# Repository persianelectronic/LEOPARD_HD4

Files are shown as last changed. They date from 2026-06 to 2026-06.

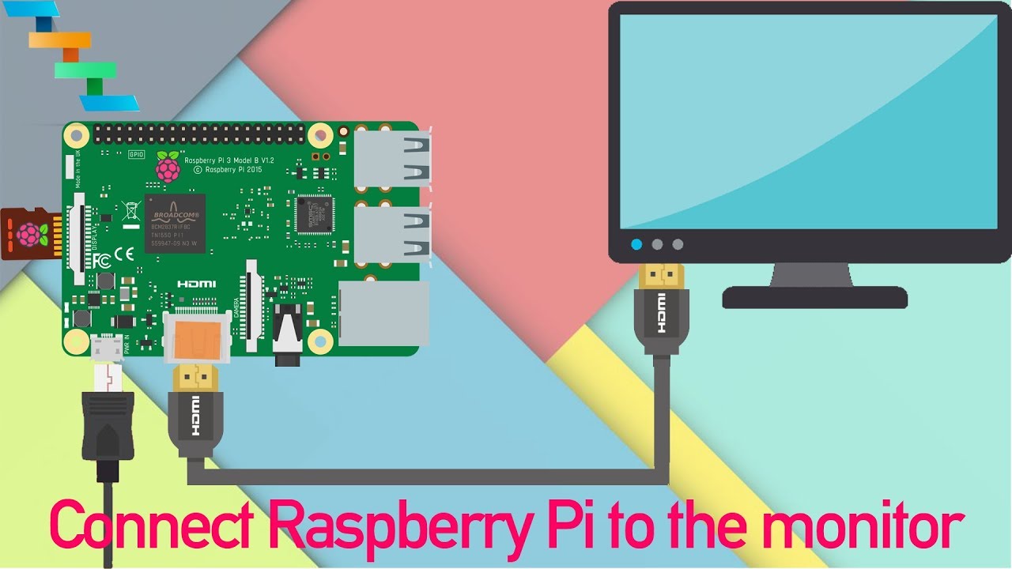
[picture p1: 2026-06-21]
Image/HDMI TI MONITOR.jpg

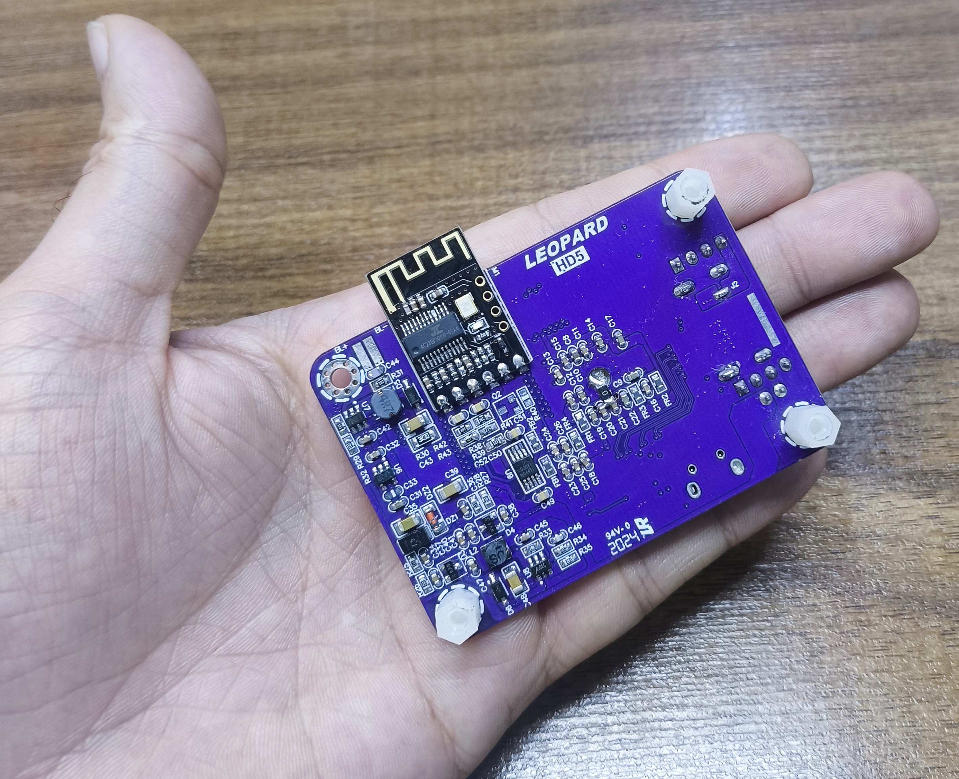
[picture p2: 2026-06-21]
Image/IMG_20260621_094336.jpg

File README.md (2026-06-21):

s-l400Texas Instruments_TFP401AIPZPR-1_2736

612SBk9E+4L

HDMI

#### 📂 فایل‌های پروژه

- 🟣 انتشار رایگان فایل‌های شماتیک (Schematic) و PCB  
- 🟣 ارائه فایل‌های اصلی پروژه در Altium Designer  
- 🟣 دسترسی به فایل‌های تولید برد (Gerber) و مستندات فنی  
- 🟣 طراحی کاملاً متن‌باز و قابل توسعه برای همگان  

<br>

- 🟣 ارائه کامل فایل‌های EDID و فایل‌های باینری آماده  
- 🟣 آموزش برنامه‌ریزی و شخصی‌سازی EDID با آردوینو  
- 🟣 مستندات فنی جهت راه‌اندازی و توسعه پروژه  

<br>

#### ⚙️ مشخصات فنی

- 🟣 مبتنی بر تراشه قدرتمند TFP401 از شرکت Texas Instruments  
- 🟣 مبدل HDMI/DVI به RGB Parallel برای نمایشگرهای TFT  
- 🟣 طراحی فشرده، کاربردی و قابل تولید  
- 🟣 مناسب برای پروژه‌های آموزشی، تحقیقاتی و صنعتی  

<br>

#### 🎯 کاربردها

- 🟣 مناسب برای مهندسان، دانشجویان و علاقه‌مندان به سیستم‌های امبدد و پردازش تصویر  
- 🟣 ایده‌آل برای توسعه نمایشگرهای TFT مبتنی بر HDMI  
- 🟣 قابل استفاده در پروژه‌های صنعتی، آزمایشگاهی و آموزشی  

<br>

#### 👨‍💻 توسعه‌دهنده

- 🟣 طراحی و توسعه توسط شرکت Persian Electronic Poya  
- 🟣 پروژه‌ای متن‌باز با هدف گسترش دانش سخت‌افزار و اشتراک‌گذاری تجربیات مهندسی  

<br>

#### 🌟 ویژگی‌ها

- 🟣 Open Source Hardware  
- 🟣 Altium Designer Project Files Included  
- 🟣 Free Schematic & PCB Files  
- 🟣 Free EDID Resources  
- 🟣 Powered by Texas Instruments TFP401  

---

<div align="center">

🚀 **سخت‌افزار آزاد • دانش آزاد • آینده‌ای باز** 🚀

</div>



Screenshot (168)
Screenshot (167)
Screenshot (166)
LEOPARD_HD4
Screenshot (169)
Screenshot (171)

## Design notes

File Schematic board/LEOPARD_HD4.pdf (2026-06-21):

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
ب.ظ 08:23:45 30/03/1405

### D:\Project_office\LEOPARD_HD4\LEOPARD_HD4\TOP.SchDoc

### Title:

Size: | Number:

### Date:

### File:

### Revision:

Time: | Sheet | of

A4

Drawn By: saeed kolivand | Checked By: yes

### License: altium Email: pepoya.info@gmail.com

### Page Contents: TOP.SchDoc

### Website:

# TOP

### www.pepoya.ir

# پرشین الکترونیک پویا

# PEPOYA

### CTP

### AMP

### USB_DATA

### TOP MAIN.SchDoc

### TFT USB_DATA

### TOP_TFP401 TFP401.SchDoc

TFT | CTP

### TOP_LCD LCD.SchDoc

### AMP

### TOP_AUDIO AUDIO.SchDoc

### CTP USB_DATA

### TOP_TP TCP.SchDoc

D D

C C

B B

A A

2

1 1
ب.ظ 08:23:45 30/03/1405

### D:\Project_office\LEOPARD_HD4\LEOPARD_HD4\MAIN.SchDoc

### Title:

Size: | Number:

### Date:

### Revision:

Time: | Sheet | of

A4

Drawn By: saeed kolivand | Checked By: yes

### License: altium Email: pepoya.info@gmail.com

### Page Contents: MAIN.SchDoc

### Website:

# MCU

### www.pepoya.ir

# پرشین الکترونیک پویا

# PEPOYA

0.1uF

C2
3V3M | GND

3V3M

### DATA_P

### DATA_N

### USB

### USB_DATA TOP[2B], TCP[3D], TFP401[8A] DATA_N

### DATA_P

### DATA_N

### CH554G

### P3.2/TXD1_/INT0/VBUS1/AIN3 1 P1.4/T2_/CAP1_/SCS/TIN2/UCC1/AIN1 2 P1.5/MOSI/PWM1/TIN3/UCC2/AIN2 3 P1.6/MISO/RXD1/TIN4 4 P1.7/SCK/TXD1/TIN5 5 RST/T2EX_/CAP2_ 6 P3.1/PWM2_/TXD 7 P3.0/PWM1_/RXD 8

P1.1/T2EX/CAP2/TIN1/VBUS2/AIN0 | | | | | | | 9
P3.3/INT1 | 10 P3.4/PWM2/RXD1_/T0 | 11 P3.6/UDP | 12 P3.7/UDM | 13 GND/VSS | 14 VCC/VDD | 15 V33 | 16

U1

### DATA_P

GND | 0603

R2 10K
3V3M

### CTP_INT CTP_SCL CTP_SDA CTP_RST

### TX_MCU RX_MCU

### LED

3V3M

VI 1
INH 3 | BYP | 4
VO | 5 2

### GND

### U2 LN1134-3.3V

10UF
C3

### GND

5.0V | 0603 | C5

### 10NF ⁰⁶⁰³

C4
100NF

### GND

1
2
3
4

### TTL

### HDR1X4

3V3M

### TX_MCU

### RX_MCU

### GREEN

LD1 0603
R1

1K

GND | AMP_EN
3V3M | 0603

R3
10K

### GND

SW1

SW1

# RST_MCU 0603

R5
10K

### GND

RST_MCU | 3V3M

H1

### Round Pad

H2

### Round Pad

16

### AMP

AMP | TOP[2C], AUDIO[1B] AMP_EN

0.1uF

C1

### CTP_SDA CTP_SCL CTP_INT CTP_RST

### EN_BLK

TP

CTP | TOP[2B], LCD[3B]

### CTP_INT

### CTP_SCL

### CTP_SDA

### CTP_RST

### EN_BLK

H4

### Round Pad

H3

### Round Pad

### EN_BLK

### OFF/ON

SW1

### RST

SW2

### BOOT

SW3

### BOOT

EP 101 | Clock And Control | Signals OOD Pixel Output EVEN Pixel Output DVI / HDMI Input TFP401 Config

# VDD⁰⁶⁰³

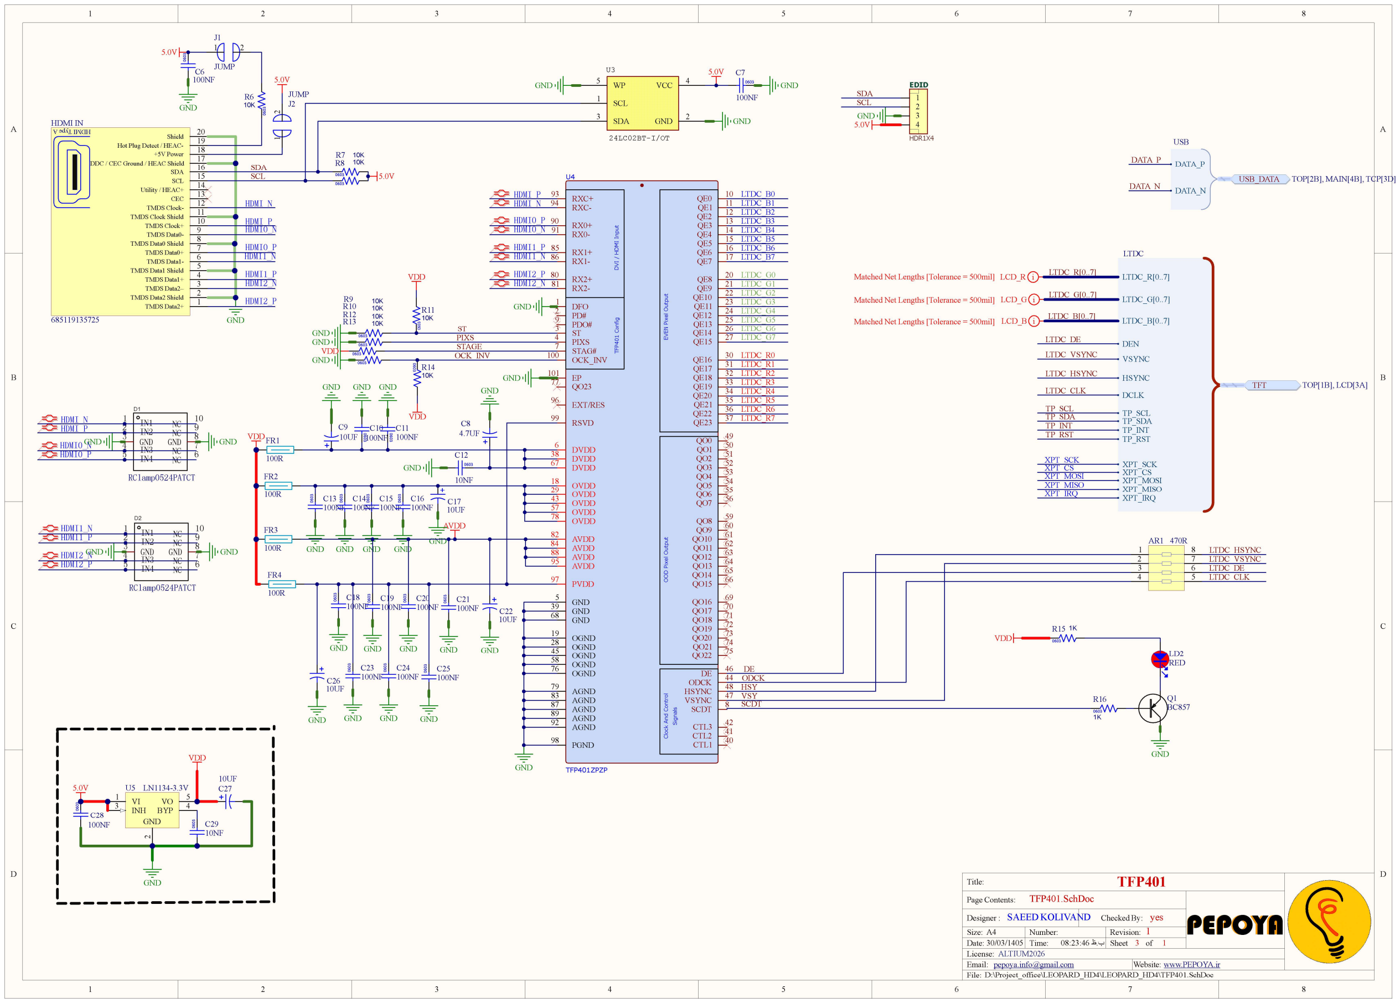
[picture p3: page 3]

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
ب.ظ 08:23:46 30/03/1405

D:\Project_office\LEOPARD_HD4\LEOPARD_HD4\TFP401.SchDoc

Title:

Size: | Number:
Date:

Revision:
Time: | Sheet | of

A4

Designer : SAEED KOLIVAND Checked By: yes

License: ALTIUM2026
Email: pepoya.info@gmail.com

Page Contents: TFP401.SchDoc

Website: www.PEPOYA.ir

# TFP401

# PEPOYA

DFO 1
PD# 2

ST 3
PIXS 4

GND 5

DVDD 6

STAG# 7

SCDT 8

PDO# 9

QE0 | 10
QE1 | 11
QE2 | 12
QE3 | 13
QE4 | 14
QE5 | 15
QE6 | 16
QE7 | 17

OVDD 18

OGND 19

QE8 | 20
QE9 | 21
QE10 | 22
QE11 | 23
QE12 | 24
QE13 | 25
QE14 | 26
QE15 | 27

OGND 28

OVDD 29

QE16 | 30
QE17 | 31
QE18 | 32
QE19 | 33
QE20 | 34
QE21 | 35
QE22 | 36
QE23 | 37

DVDD 38

GND 39

CTL1 | 40 CTL2 | 41 CTL3 | 42

OVDD 43

ODCK 44

OGND 45

DE | | 46
VSYNC | 47 HSYNC | 48
QO0 | 49
QO1 | 50
QO2 | 51
QO3 | 52
QO4 | 53
QO5 | 54
QO6 | 55
QO7 | 56
OVDD 57

OGND 58

QO8 | 59
QO9 | 60
QO10 | 61
QO11 | 62
QO12 | 63
QO13 | 64
QO14 | 65
QO15 | 66

DVDD 67

GND 68

QO16 | 69
QO17 | 70
QO18 | 71
QO19 | 72
QO20 | 73
QO21 | 74
QO22 | 75

OGND 76

QO23 77

OVDD 78

AGND 79

RX2+ 80
RX2- 81

AVDD 82

AGND 83

AVDD 84

RX1+ 85
RX1- 86

AGND 87

AVDD 88

AGND 89

RX0+ 90
RX0- 91

AGND 92

RXC+ 93
RXC- 94

AVDD 95

EXT/RES 96

PVDD 97

PGND 98

RSVD 99

OCK_INV 100

U4

GND | TFP401ZPZP

FR1

100R

FR2

100R

FR3

100R

FR4

100R

R6
10K | 0603 | C19

100NF ⁰⁶⁰³ C20
100NF 0603 | C21 100NF
GND | GND | GND ⁰⁶⁰³ C18
100NF
GND | 0603 | C15 100NF

GND ⁰⁶⁰³ C13
100NF
GND | 0603 | C14 100NF
GND | 0603 | C16 100NF

# GND ⁰⁶⁰³

C10
100NF
GND | 0603

C11
100NF

GND

AVDD

TMDS Data2+ | 1
TMDS Data2 Shield | 2
TMDS Data2– | 3
TMDS Data1+ | 4
TMDS Data1 Shield | 5
TMDS Data1- | 6
TMDS Data0+ | 7
TMDS Data0 Shield | 8
TMDS Data0- | 9
TMDS Clock+ | 10 TMDS Clock Shield | 11 TMDS Clock- | 12 CEC | 13 Utility / HEAC+ | 14 SCL | 15 SDA | 16 DDC / CEC Ground / HEAC Shield | 17 ⁺⁵V Power | 18 Hot Plug Detect / HEAC- | 19 Shield | 20 HDMI Type A

HDMI IN

685119135725

5.0V

SDA
SCL

GND

GND

0603

R8 10K

0603

R7 10K

5.0V

GND

0603

R9 10K

0603

R10 10K

0603

R13 10K

0603

R12 10K

VDD

ODCK
HSY
VSY

LCD_R i

Matched Net Lengths [Tolerance = 500mil]

Matched Net Lengths [Tolerance = 500mil] LCD_G i

LCD_B i

Matched Net Lengths [Tolerance = 500mil]

TFT | TOP[1B], LCD[3A]

LTDC_R[0..7]

LTDC_G[0..7]

LTDC_B[0..7]

DEN
VSYNC

HSYNC

DCLK

TP_SCL
TP_SDA
TP_INT
TP_RST

XPT_SCK
XPT_CS
XPT_MOSI
XPT_MISO
XPT_IRQ

LTDC

LTDC_R[0..7]

LTDC_G[0..7]

LTDC_B[0..7]

TP_INT
TP_RST

TP_SCL
TP_SDA

LTDC_CLK

LTDC_VSYNC

LTDC_HSYNC

LTDC_DE

XPT_SCK
XPT_CS
XPT_MOSI
XPT_MISO
XPT_IRQ

LTDC_CLK

LTDC_VSYNC

LTDC_HSYNC

LTDC_DE

1

5

8

4

7
3 6

2

AR1 470R

SCDT

LTDC_R1
LTDC_R2
LTDC_R3
LTDC_R4
LTDC_R5
LTDC_R6
LTDC_R7

LTDC_R0

LTDC_G1
LTDC_G2
LTDC_G3
LTDC_G4
LTDC_G5
LTDC_G6
LTDC_G7

LTDC_G0

LTDC_B1
LTDC_B2
LTDC_B3
LTDC_B4
LTDC_B5
LTDC_B6
LTDC_B7

LTDC_B0

DE

10UF

C22

GND

10UF

C9

GND

4.7UF

C8

GND

0603

C12

10NF

GND

GND

10UF

C17 0603 C25

100NF

GND | GND | GND ⁰⁶⁰³ C23

100NF ⁰⁶⁰³ C24
100NF
10UF

C26

GND

0603

C7

100NF

5.0V
GND

GND

GND | WP 5

SCL 1

SDA 3

VCC | 4
GND | 2

U3

24LC02BT-I/OT

1 2

J1

JUMP

PIXS
STAGE

ST

OCK_INV

GND

GND

GND

0603

R16

1K

DATA_P

DATA_N

USB

USB_DATA TOP[2B], MAIN[4B], TCP[3D]

5.0V ⁰⁶⁰³
C6
100NF
GND | 1 2

J2

JUMP

DATA_N

DATA_P

Q1
BC857

GND

RED

LD2

0603

R15 1K
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
EDID

HDR1X4

5.0V

VI 1
INH 3 | BYP | 4
VO | 5 2

GND

U5 LN1134-3.3V

10UF
C27

GND

5.0V | 0603 | C29

10NF ⁰⁶⁰³
C28
100NF

VDD

IN1 1
IN2 2
GND 3
IN3 4
IN4 5
NC | 6
NC | 7
GND | 8
NC | 9
NC | 10

D2

RClamp0524PATCT

HDMI_N | IN1 1
IN2 2
GND 3
IN3 4
IN4 5
NC | 6
NC | 7
GND | 8
NC | 9
NC | 10

D1

RClamp0524PATCT

HDMI_P

HDMI0_N
HDMI0_P

HDMI1_N
HDMI1_P

HDMI2_N
HDMI2_P

GND

GND

HDMI_N

HDMI_P
HDMI0_N

HDMI0_P
HDMI1_N

HDMI1_P
HDMI2_N

HDMI2_P

GND

GND

HDMI_N

HDMI_P

HDMI0_N

HDMI0_P

HDMI1_N

HDMI1_P

HDMI2_N

HDMI2_P 0603 R11

10K

# VDD0603 R14

10K

VDD

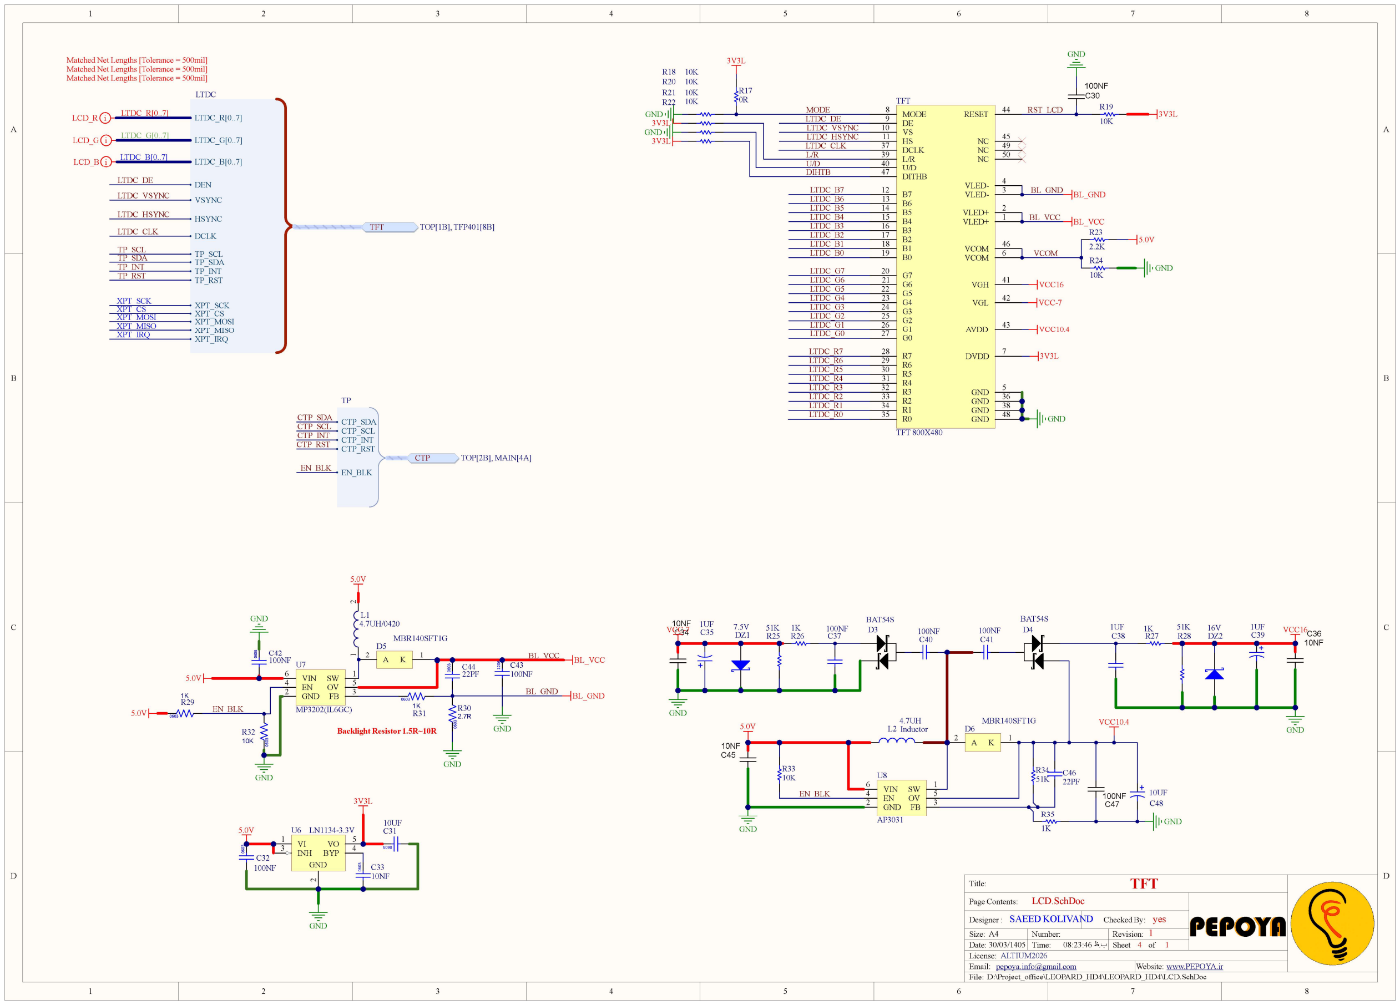
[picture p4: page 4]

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
ب.ظ 08:23:46 30/03/1405

D:\Project_office\LEOPARD_HD4\LEOPARD_HD4\LCD.SchDoc

Title:

Size: | Number:
Date:

Revision:
Time: | Sheet | of

A4

Designer : SAEED KOLIVAND Checked By: yes

License: ALTIUM2026
Email: pepoya.info@gmail.com

Page Contents: LCD.SchDoc

Website: www.PEPOYA.ir

# TFT

# PEPOYA

3V3L

100NF
C30
MODE 8
DE 9
VS 10
HS 11

L/R 39
U/D 40
DITHB 47

B7 12
B6 13
B5 14
B4 15
B3 16
B2 17
B1 18
B0 19

G7 20
G6 21
G5 22
G4 23
G3 24
G2 25
G1 26
G0 27

R7 28
R6 29
R5 30
R4 31
R3 32
R2 33
R1 34
R0 35 | GND | 48 GND | 38 GND | 36 GND | 5
| DVDD | | | | 7
AVDD | 43
VGL | 42
VGH | 41
VCOM | 6
VCOM | 46
VLED+ | 1
VLED+ | 2
VLED- | 3
VLED- | | | 4
NC | 50 NC | 49 NC | 45
RESET | 44

DCLK 37

TFT

TFT 800X480

L/R
U/D
DIHTB

BL_GND BL_GND

BL_VCC BL_VCC

VCOM
GND

VCC16

VCC-7

VCC10.4

3V3L

GND

MODE | 3V3L

GND

R17
0R
GND
3V3L
GND
3V3L

R19
10K

R23
2.2K
R24
10K

RST_LCD

D3

BAT54S
1UF
C39
10NF

C36 D4

BAT54S 1UF
C35

10NF
C34 | DZ1 7.5V
DZ2

16V

GND
4.7UH
L2 Inductor

10NF
C45

VCC10.4

SW 1

GND 2

FB | 3
EN 4 | OV | 5

VIN 6

U8

AP3031
GND

100NF
C47

10UF
C48

R34
51K

GND

C46
22PF

C37

100NF
C40

100NF
C41
100NF | C38 1UF
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
### 1 A

2

D6

MBR140SFT1G

R33
10K
VCC-7 | VCC16

R35
1K

LTDC_R0

LTDC_R1

LTDC_R2

LTDC_R3

LTDC_R4

LTDC_R5

LTDC_R6

LTDC_R7

LTDC_G0

LTDC_G1

LTDC_G2

LTDC_G3

LTDC_G4

LTDC_G5

LTDC_G6

LTDC_G7

LTDC_B0

LTDC_B1

LTDC_B2

LTDC_B3

LTDC_B4

LTDC_B5

LTDC_B6

LTDC_B7

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
LCD_R i

Matched Net Lengths [Tolerance = 500mil]

LCD_G i

Matched Net Lengths [Tolerance = 500mil]

LCD_B i

Matched Net Lengths [Tolerance = 500mil]

TFT | TOP[1B], TFP401[8B]

LTDC_R[0..7]

LTDC_G[0..7]

LTDC_B[0..7]

DEN
VSYNC

HSYNC

DCLK

TP_SCL
TP_SDA
TP_INT
TP_RST

XPT_SCK
XPT_CS
XPT_MOSI
XPT_MISO
XPT_IRQ

LTDC

LTDC_R[0..7]

LTDC_G[0..7]

LTDC_B[0..7]

TP_INT
TP_RST

TP_SCL
TP_SDA

LTDC_CLK

LTDC_VSYNC

LTDC_HSYNC

LTDC_DE

XPT_SCK
XPT_CS
XPT_MOSI
XPT_MISO
XPT_IRQ

GND

GND

BL_VCC

BL_GND

GND

BL_VCC
SW 1

GND 2

FB | 3
EN 4 | OV | 5

VIN 6

U7

MP3202(IL6GC)

BL_GND

Backlight Resistor 1.5R~10R

0603

R29

1K | 0603

R32
10K

0603
R31
1K | 0603 R30
2.7R ⁰⁶⁰³ | C42
100NF | 0603 | C44

22PF ¹ ² L1

4.7UH/0420 | 1206 | C43

100NF

GND

5.0V

LTDC_DE
LTDC_VSYNC
LTDC_HSYNC
LTDC_CLK

CTP_SDA
CTP_SCL
CTP_INT
CTP_RST

EN_BLK

TP

CTP | TOP[2B], MAIN[4A]

CTP_INT

CTP_SCL

CTP_SDA

CTP_RST

VI 1
INH 3 | BYP | 4
VO | 5 2

GND

U6 LN1134-3.3V

GND | 0603 | C33

10NF ⁰⁶⁰³
C32
100NF

3V3L

5.0V

5.0V

5.0V

5.0V

5.0V

K

### 1 A

2

D5

MBR140SFT1G

EN_BLK 0603

C31

10UF

EN_BLK

EN_BLK

D D

C C

B B

A A

5

1 1
ب.ظ 08:23:46 30/03/1405

### D:\Project_office\LEOPARD_HD4\LEOPARD_HD4\TCP.SchDoc

### Title:

Size: | Number:

### Date:

### Revision:

Time: | Sheet | of

A4

Drawn By: saeed kolivand | Checked By: yes

### License: altium Email: pepoya.info@gmail.com

### Page Contents: TCP.SchDoc

### Website:

# TCP

### www.pepoya.ir

# پرشین الکترونیک پویا

# PEPOYA

### GND

1
2
3
4
5
6

TP1

### FFC6/PIN

3V3M 0603

R37

10K 0603

R36
10K

3V3M

1
2
3
4
5
6

TP2

### FFC6/PIN

### GND

### CTP_INT

### CTP_SCL

### CTP_SDA

### CTP_RST

### CTP_INT

### CTP_SCL CTP_SDA

### CTP_RST 3V3M

### DATA_P

### DATA_N

### USB

### USB_DATA TOP[2C], MAIN[4B], TFP401[8A] DATA_N

### DATA_P

EH 6

GND | 5
ID | 4
D+ | 3
D- | 2
VCC | 1

### USB Micro Input

### GND

### GND

### DATA_N DATA_P

5.0V

### CTP_SDA CTP_SCL CTP_INT CTP_RST

### EN_BLK

TP

CTP | TOP[1C]

### CTP_INT

### CTP_SCL

### CTP_SDA

### CTP_RST

### EN_BLK ¹

2

### VCC_USB HEADRE 1X2

D D

C C

B B

A A

6

1 1
ب.ظ 08:23:47 30/03/1405

### D:\Project_office\LEOPARD_HD4\LEOPARD_HD4\AUDIO.SchDoc

### Title:

Size: | Number:

### Date:

### Revision:

Time: | Sheet | of

A4

Drawn By: saeed kolivand | Checked By: yes

### License: altium Email: pepoya.info@gmail.com

### Page Contents: AUDIO.SchDoc

### Website:

# AUDIO/AMP

### www.pepoya.ir

# پرشین الکترونیک پویا

# PEPOYA

### SPK1-

0603

### C52 1UF

0603

R42

20K

0603

### C50 1UF

0603
R41
20K

### GND

### CTRL 1

### BYPASS 2

IN+ 3

IN- 4 | VOUT1 | 5
| VDD | 6
GND | 7
VOUT2 | 8

U9

### 8002B/FT690M

0603

C49

1UF

### GND 0603 R38

10K

0603

20K R39

0603

20K R43

### SPK1+

FB1

FB2

SP1-

SP1+

4.2V

4.2V

### AMP_EN

### LEFT

### RIGHT

0603

### C51 1UF

### GND Q2

S8050

### GND

### CTRL

KEY | 1
MUTE | 2
VCC | 3
GND | 4
LEFT | 5
RIGHT MH⁻M¹⁸ | 6

M1

M18

4.2V

### GND LEFT

### RIGHT

0603

R40

1K

16

### AMP

AMP | TOP[2C], MAIN[4B] AMP_EN

VI 1
INH 3 | BYP | 4
VO | 5 2

### GND

### U10 LN1134-3.3V

GND | 0603 | C55

### 10NF ⁰⁶⁰³

C54
100NF

5.0V

4.2V

10UF

C53

4.2V

1
2

### SPK

### ZH 1X2

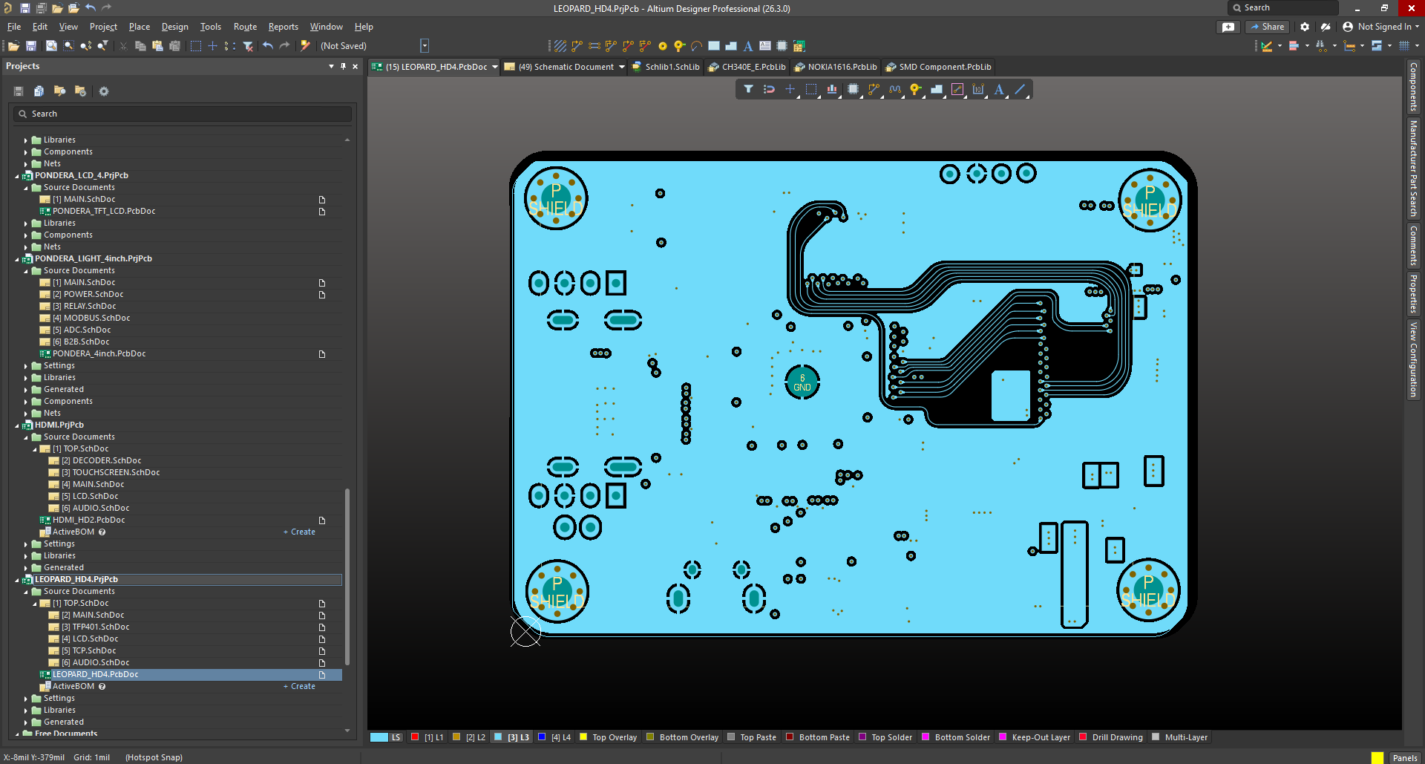
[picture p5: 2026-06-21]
Image/Screenshot (168).png

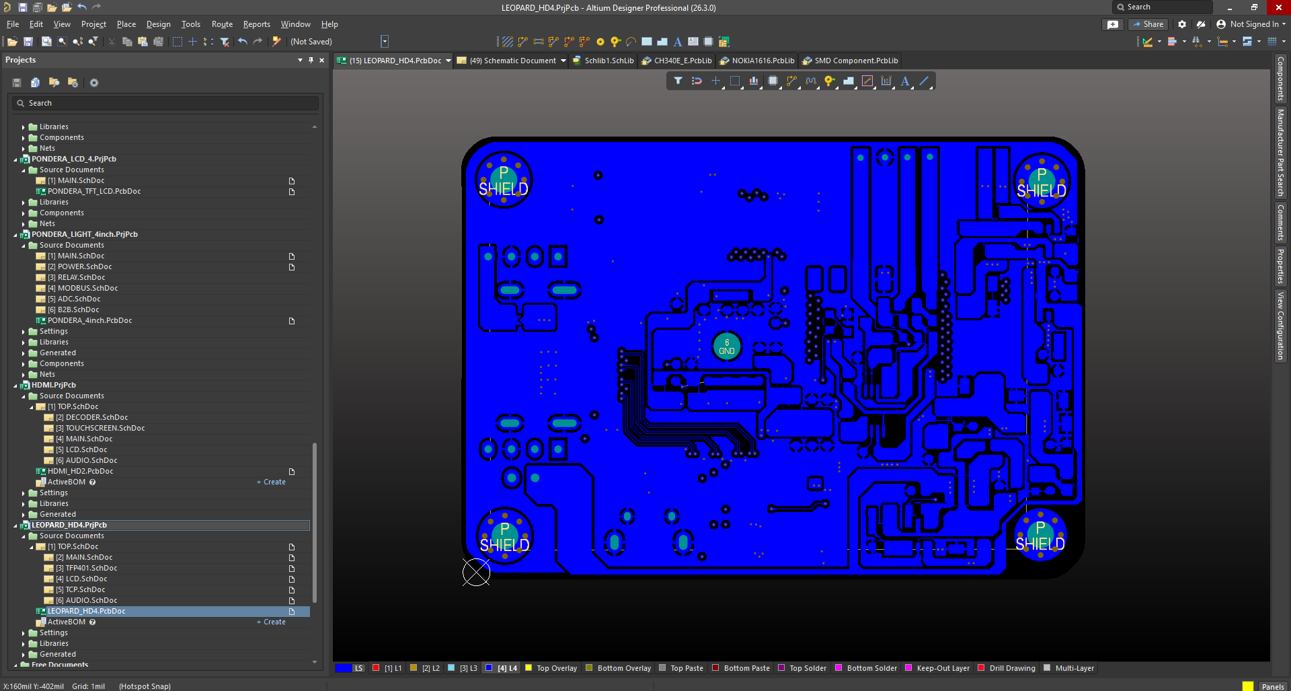
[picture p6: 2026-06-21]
Image/Screenshot (169).png

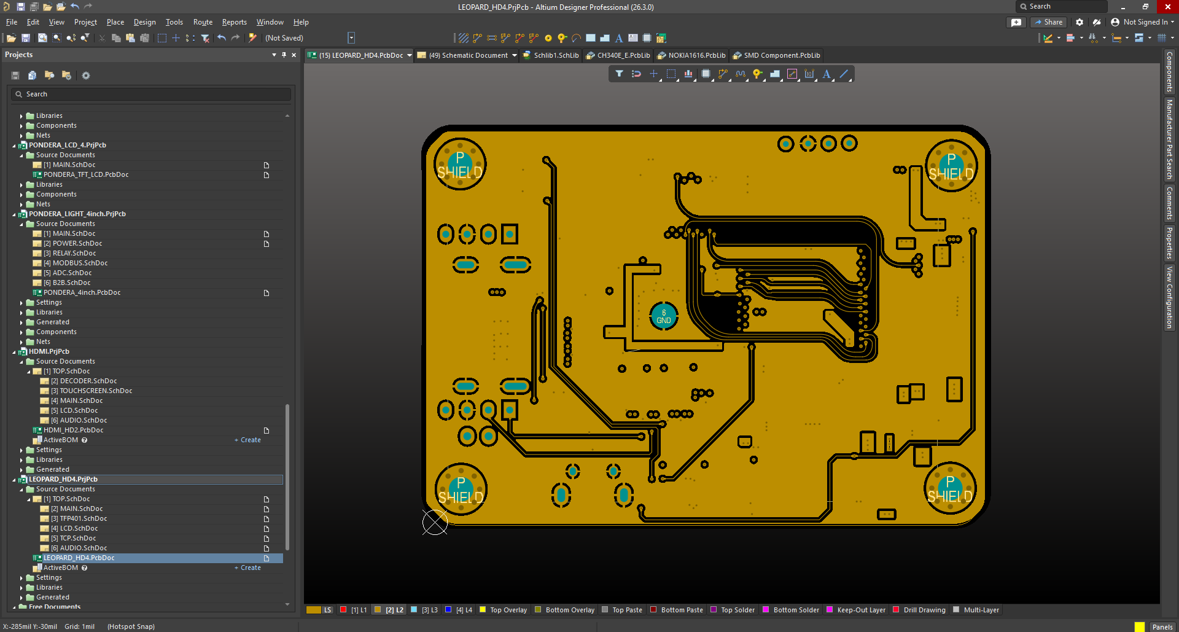
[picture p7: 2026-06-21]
Image/Screenshot (167).png

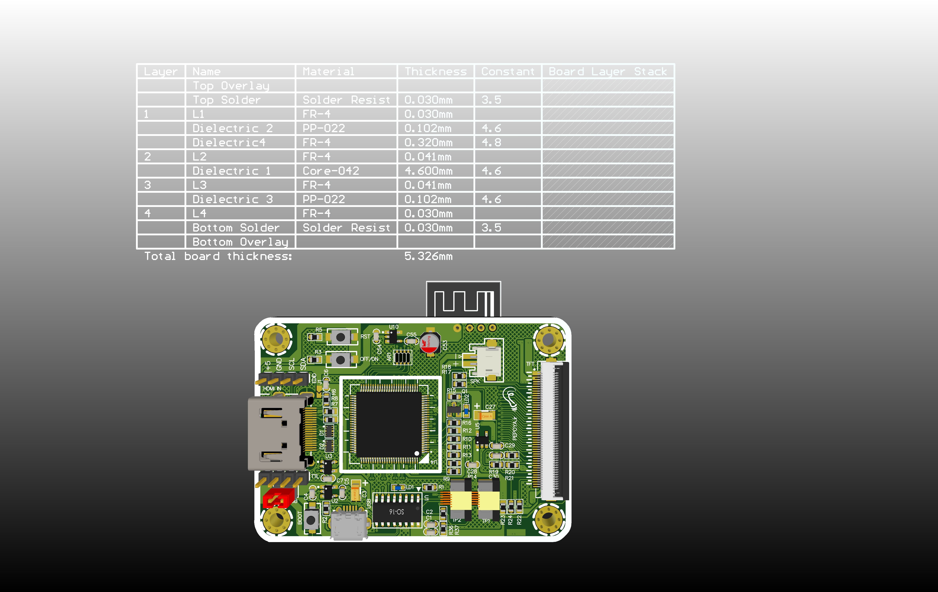
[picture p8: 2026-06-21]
Image/LEOPARD_HD4.jpg

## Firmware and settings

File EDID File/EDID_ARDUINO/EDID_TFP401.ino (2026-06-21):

#include <Wire.h> //I2C library



/*
const uint8_t PROGMEM eepromdat[128] = {
    // Header
    0x00, 0xFF, 0xFF, 0xFF, 0xFF, 0xFF, 0xFF, 0x00,
    // Manufacturer ID ('PEK'), Product Code, Serial Number
    0x50, 0x45, 0x4B, 0x01, 0x00, 0x00, 0x00, 0x00,
    // EDID Version & Basic Display Parameters
    0x01, 0x1A, 0x01, 0x03, 0x80, 0x28, 0x17, 0x78,
    0x0A, 0xCF, 0x74, 0xA0, 0x57, 0x4C, 0x9E, 0x25,
    0x12, 0x48, 0x4C, 0x00, 0x00, 0x00, 0x01, 0x01,
    // Supported Features
    0x01, 0x01, 0x01, 0x01, 0x01, 0x01, 0x01, 0x01,
    // Detailed Timing Descriptor for 480x272 @60Hz
    0x02, 0x1C, 0x30, 0xE0, 0x2D, 0x10, 0x28, 0x30,
    0xD3, 0x00, 0x9A, 0x32, 0x00, 0x00, 0x00, 0x18,
    // Display Name Descriptor (پرشین الکترونیک)
    0x00, 0x00, 0x00, 0xFC, 0x00, 0x50, 0x65, 0x72,
    0x73, 0x69, 0x61, 0x6E, 0x20, 0x45, 0x6C, 0x65,
    0x63, 0x74, 0x72, 0x6F, 0x6E, 0x69, 0x63, 0x00,
    // Monitor Range Limits
    0x00, 0x00, 0x00, 0xFD, 0x00, 0x32, 0x4C, 0x1E,
    0x53, 0x00, 0x0A, 0x20, 0x20, 0x20, 0x20, 0x20,
    0x20, 0x01, 0x37,
    // Padding & Checksum
    0x00, 0x00, 0x00, 0x00, 0x00, 0x00, 0x00, 0x00
};
*/




// 480x272 @ 25mhz

const uint8_t PROGMEM eepromdat[128] = {
0x00, 0xFF, 0xFF, 0xFF, 0xFF, 0xFF, 0xFF, 0x00, 0x04, 0x81, 0x43, 0x00, 0x01, 0x00, 0x00, 0x00, 
0x0C, 0x17, 0x01, 0x03, 0x81, 0x0A, 0x06, 0x78, 0x8A, 0xA5, 0x8E, 0xA6, 0x54, 0x4A, 0x9C, 0x26, 
0x12, 0x45, 0x46, 0x00, 0x00, 0x00, 0x01, 0x01, 0x01, 0x01, 0x01, 0x01, 0x01, 0x01, 0x01, 0x01, 
0x01, 0x01, 0x01, 0x01, 0x01, 0x01, 0xC4, 0x09, 0xE0, 0x33, 0x10, 0x10, 0x14, 0x10, 0x08, 0x05, 
0x4A, 0x00, 0x5F, 0x36, 0x00, 0x00, 0x00, 0x18, 0x00, 0x00, 0x00, 0xFC, 0x00, 0x41, 0x44, 0x41, 
0x46, 0x52, 0x55, 0x49, 0x54, 0x20, 0x34, 0x33, 0x20, 0x20, 0x00, 0x00, 0x00, 0x10, 0x00, 0x00, 
0x00, 0x00, 0x00, 0x00, 0x00, 0x00, 0x00, 0x00, 0x00, 0x00, 0x00, 0x00, 0x00, 0x00, 0x00, 0x10, 
0x00, 0x00, 0x00, 0x00, 0x00, 0x00, 0x00, 0x00, 0x00, 0x00, 0x00, 0x00, 0x00, 0x00, 0x00, 0x42
};


/*
const uint8_t PROGMEM eepromdat[128] = {
  0x00, 0xFF, 0xFF, 0xFF, 0xFF, 0xFF, 0xFF, 0x00, 0x5C, 0x34, 0x01, 0x00, 0x01, 0x00, 0x00, 0x00,
  0x01, 0x19, 0x01, 0x03, 0x81, 0x00, 0x00, 0x00, 0x0A, 0x00, 0x00, 0x00, 0x00, 0x00, 0x00, 0x00,
  0x00, 0x00, 0x00, 0x00, 0x00, 0x00, 0x01, 0x01, 0x01, 0x01, 0x01, 0x01, 0x01, 0x01, 0x01, 0x01,
  0x01, 0x01, 0x01, 0x01, 0x01, 0x01, 0xC4, 0x09, 0xE0, 0x33, 0x10, 0x10, 0x14, 0x10, 0x08, 0x05,
  0x4A, 0x00, 0xE0, 0x10, 0x11, 0x00, 0x00, 0x18, 0x00, 0x00, 0x00, 0xFC, 0x00, 0x48, 0x44, 0x4D,
  0x49, 0x20, 0x44, 0x49, 0x53, 0x50, 0x4C, 0x41, 0x59, 0x0A, 0x00, 0x00, 0x00, 0x10, 0x00, 0x01,
  0x00, 0x0A, 0x00, 0x0A, 0x00, 0x0A, 0x0A, 0x0A, 0x0A, 0x0A, 0x20, 0x0A, 0x00, 0x00, 0x00, 0x10,
  0x00, 0x00, 0x00, 0x00, 0x00, 0x00, 0x00, 0x00, 0x00, 0x00, 0x00, 0x00, 0x00, 0x00, 0x00, 0x38
};
*/



/* TFT 800x480 ! */    //1                            800x480
/*
const uint8_t PROGMEM eepromdat[128] = {
0x00, 0xFF, 0xFF, 0xFF, 0xFF, 0xFF, 0xFF, 0x00, 0x04, 0x81, 0x04, 0x00, 0x01, 0x00, 0x00, 0x00,
0x01, 0x11, 0x01, 0x03, 0x80, 0x0F, 0x0A, 0x00, 0x0A, 0x00, 0x00, 0x00, 0x00, 0x00, 0x00, 0x00,
0x00, 0x00, 0x00, 0x00, 0x00, 0x00, 0x01, 0x01, 0x01, 0x01, 0x01, 0x01, 0x01, 0x01, 0x01, 0x01,
0x01, 0x01, 0x01, 0x01, 0x01, 0x01, 0x80, 0x0C, 0x20, 0x80, 0x30, 0xE0, 0x2D, 0x10, 0x28, 0x30,
0xD3, 0x00, 0x6C, 0x44, 0x00, 0x00, 0x00, 0x18, 0x00, 0x00, 0x00, 0x10, 0x00, 0x00, 0x00, 0x00,
0x00, 0x00, 0x00, 0x00, 0x00, 0x00, 0x00, 0x00, 0x00, 0x00, 0x00, 0x00, 0x00, 0x10, 0x00, 0x00,
0x00, 0x00, 0x00, 0x00, 0x00, 0x00, 0x00, 0x00, 0x00, 0x00, 0x00, 0x00, 0x00, 0x00, 0x00, 0x10,
0x00, 0x00, 0x00, 0x00, 0x00, 0x00, 0x00, 0x00, 0x00, 0x00, 0x00, 0x00, 0x00, 0x00, 0x00, 0x17,
};
*/

/* TFT 800x480 ! */   //2
/*
const uint8_t PROGMEM eepromdat[128] = {
  0x00,0xFF,0xFF,0xFF,0xFF,0xFF,0xFF,0x00,0x5C,0x34,0x01,0x00,0x01,0x00,0x00,0x00,
  0x01,0x19,0x01,0x03,0x80,0x00,0x00,0x00,0x0A,0x00,0x00,0x00,0x00,0x00,0x00,0x00,
  0x00,0x00,0x00,0x00,0x00,0x00,0x01,0x01,0x01,0x01,0x01,0x01,0x01,0x01,0x01,0x01,
  0x01,0x01,0x01,0x01,0x01,0x01,0x1C,0x0C,0x20,0x80,0x30,0xE0,0x2D,0x10,0x28,0x30,
  0xD3,0x00,0x20,0xE0,0x31,0x00,0x00,0x18,0x00,0x00,0x00,0xFC,0x00,0x48,0x44,0x4D,
  0x49,0x20,0x44,0x49,0x53,0x50,0x4C,0x41,0x59,0x0A,0x00,0x00,0x00,0x10,0x00,0x00,
  0x00,0x00,0x00,0x00,0x00,0x00,0x00,0x00,0x00,0x00,0x00,0x00,0x00,0x00,0x00,0x10,
  0x00,0x00,0x00,0x00,0x00,0x00,0x00,0x00,0x00,0x00,0x00,0x00,0x00,0x00,0x00,0xB5
};
*/


/* TFT 800x480 ! */   //3
/*
const uint8_t PROGMEM eepromdat[128] = {
  0x00,0xFF,0xFF,0xFF,0xFF,0xFF,0xFF,0x00,0x5C,0x34,0x01,0x00,0x01,0x00,0x00,0x00,
  0x01,0x19,0x01,0x03,0x80,0x00,0x00,0x00,0x0A,0x00,0x00,0x00,0x00,0x00,0x00,0x00,
  
  0x00,0x00,0x00,0x00,0x00,0x00,0x01,0x01,0x01,0x01,0x01,0x01,0x01,0x01,0x01,0x01,
  0x01,0x01,0x01,0x01,0x01,0x01,0xAA,0x0A,0x20,0x42,0x30,0xE0,0x2C,0x10,0x10,0x0A,
  0x51,0x04,0x20,0xE0,0x31,0x00,0x00,0x18,0x00,0x00,0x00,0xFC,0x00,0x48,0x44,0x4D,
  0x49,0x20,0x44,0x49,0x53,0x50,0x4C,0x41,0x59,0x0A,0x00,0x00,0x00,0x10,0x00,0x00,
  0x00,0x00,0x00,0x00,0x00,0x00,0x00,0x00,0x00,0x00,0x00,0x00,0x00,0x00,0x00,0x10,
  0x00,0x00,0x00,0x00,0x00,0x00,0x00,0x00,0x00,0x00,0x00,0x00,0x00,0x00,0x00,0x24

};
*/


/* TFT 800x480 ! */   //4
/*
const uint8_t PROGMEM eepromdat[128] = {
  0x00,0xFF,0xFF,0xFF,0xFF,0xFF,0xFF,0x00,0x5C,0x34,0x01,0x00,0x01,0x00,0x00,0x00,
  0x01,0x19,0x01,0x03,0x80,0x00,0x00,0x00,0x0A,0x00,0x00,0x00,0x00,0x00,0x00,0x00,
  0x00,0x00,0x00,0x00,0x00,0x00,0x01,0x01,0x01,0x01,0x01,0x01,0x01,0x01,0x01,0x01,
  0x01,0x01,0x01,0x01,0x01,0x01,0x1C,0x0C,0x20,0x80,0x30,0xE0,0x2D,0x10,0x28,0x30,
  0xD3,0x00,0x20,0xE0,0x31,0x00,0x00,0x18,0x00,0x00,0x00,0xFC,0x00,0x48,0x44,0x4D,
  0x49,0x20,0x44,0x49,0x53,0x50,0x4C,0x41,0x59,0x0A,0x8C,0x0A,0xD0,0x6C,0x20,0xE0,
  0x1E,0x10,0x10,0x3E,0x96,0x00,0xD0,0xE0,0x21,0x00,0x00,0x18,0x00,0x00,0x00,0x10,
  0x00,0x00,0x00,0x00,0x00,0x00,0x00,0x00,0x00,0x00,0x00,0x00,0x00,0x00,0x00,0xF8
};
*/


// I2C eeprom dumper
byte i2c_eeprom_read_byte(uint8_t deviceaddress, uint16_t eeaddress );

#define EEPROMSIZE 256UL  // 0.5 Kb
#define ADDRESS_SIZE 8

byte i2c_eeprom_read_byte(uint8_t deviceaddress, uint16_t eeaddress ) {
    byte rdata = 0xFF;
#if (ADDRESS_SIZE == 16)
    Wire.beginTransmission(deviceaddress);
    Wire.write((eeaddress >> 8)); // MSB
#else
    //deviceaddress |= (eeaddress >> 8);
    Wire.beginTransmission(deviceaddress); // MSB
#endif
    Wire.write(eeaddress); // LSB
    Wire.endTransmission();
    Wire.requestFrom(deviceaddress, (uint8_t)1);
    while (!Wire.available()); 
    rdata = Wire.read();
    return rdata;
}

void i2c_eeprom_write_byte(uint8_t deviceaddress, uint16_t eeaddress, byte data ) {
#if (ADDRESS_SIZE == 16)
    Wire.beginTransmission(deviceaddress);
    Wire.write((eeaddress >> 8)); // MSB
#else
    //deviceaddress |= (eeaddress >> 8);
    Wire.beginTransmission(deviceaddress); // MSB
#endif
    Wire.write((byte)eeaddress); // LSB
    Wire.write((byte)data);
    Wire.endTransmission();
}
  

void setup() {
  Wire.begin(); // initialise the connection
  Serial.begin(9600);
  Serial.println(F("EEPROM WRITER"));
  Serial.print(F("EEPROM data size: "));
  Serial.println(sizeof(eepromdat));
  Serial.println(F("Hit any key & return to start"));
  while (!Serial.available());
  byte b;
  Serial.println("Starting");
  for (uint16_t addr = 0; addr < EEPROMSIZE; addr++) {
    if (addr < sizeof(eepromdat)) {
      b = pgm_read_byte(eepromdat+addr);
    } else {
      b = 0xFF;
    }
     i2c_eeprom_write_byte(0x50, addr, b);
     delay(5);
     if ((addr % 32) == 0)
       Serial.println();
     Serial.print("0x");
     if (b < 0x10) Serial.print('0');
     Serial.print(b, HEX); //print content to serial port
     Serial.print(", ");
  }
  Serial.println("\n\r========\n\rFinished!");
  for (uint16_t addr = 0; addr < EEPROMSIZE; addr++) {
    if (addr < sizeof(eepromdat)) {
      b = pgm_read_byte(eepromdat+addr);
    } else {
      b = 0xFF;
    }
    uint8_t d =  i2c_eeprom_read_byte(0x50, addr);
    if ((addr % 32) == 0)
      Serial.println();
    Serial.print("0x");
    if (d < 0x10) Serial.print('0');
    Serial.print(d, HEX); //print content to serial port
    Serial.print(", ");

    if (b != d) {
       Serial.print(F("verification failed at 0x")); Serial.println(addr);
       while (1);
     }
  }
  Serial.println(F("\n\r\n\rVerified!"));
}

void loop() {
}

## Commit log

2026-06-21 Schematic file
2026-06-21 PCB Board
    [LEOPARD_HD4.PcbDoc]
